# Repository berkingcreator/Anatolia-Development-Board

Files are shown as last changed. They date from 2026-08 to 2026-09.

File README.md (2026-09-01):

# Anatolia Geliştirme Kart Serisi

<p align="center">
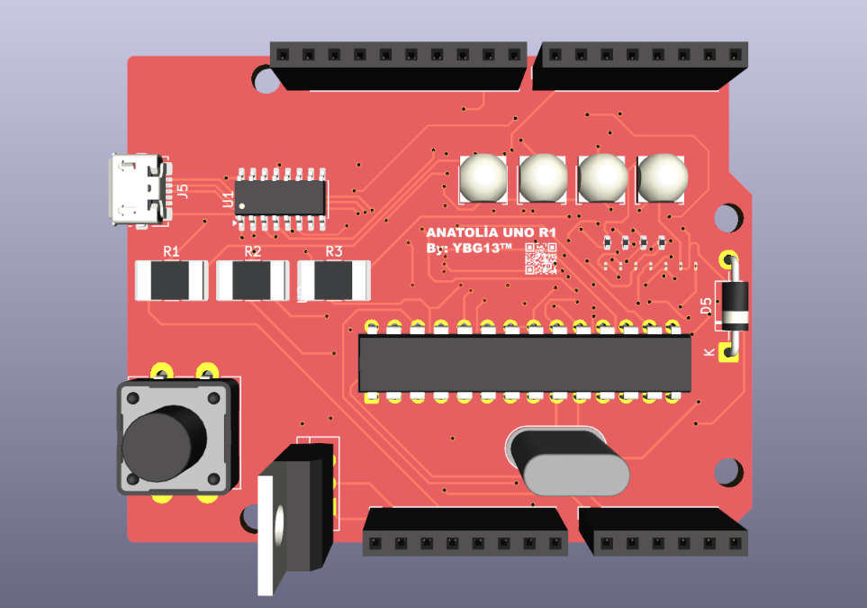
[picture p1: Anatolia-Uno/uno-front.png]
Anatolia Uno Ön Yüz
  
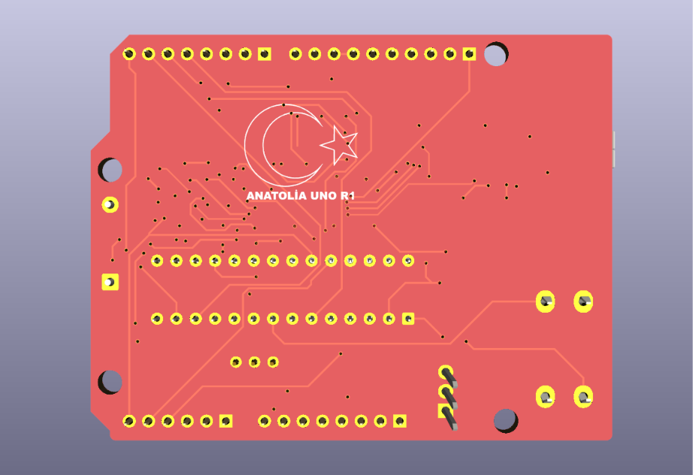
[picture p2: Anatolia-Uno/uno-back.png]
Anatolia Uno Arka Yüz
  
</p>

**Anatolia Geliştirme Kart Serisi**, açık kaynaklı mikrodenetleyici mimarilerini ve AVR (ATmega ve ATtiny) çekirdeklerini temel alan, yerli ve modüler bir geliştirme donanımı ailesidir. Düşük güç tüketimi gerektiren gömülü sistemlerden lojik devre simülasyonlarına, giyilebilir teknolojilerden hafif otonom modüllere kadar geniş bir yelpazede esnek çözümler sunar.

---

## 🚀 Öne Çıkan Özellikler

* **Açık Kaynak Donanım & Mimari:** Tamamen açık kaynaklı şematik ve donanım tasarımı ile özelleştirilebilir yapı.
* **Geniş Çekirdek Desteği:** İhtiyaca göre ölçeklenebilen ATmega328P ve ATtiny85 / ATtiny84 tabanlı yüksek verimli mikrodenetleyici entegrasyonu.
* **Kompakt Form Faktörü:** Minimal alan kaplayan, breadboard ve özel PCB uygulamalarına kolayca entegre edilebilir yapı.
* **Dahili Bootloader Desteği:** Optiboot ve Micronucleus / V-USB bootloader destekleri sayesinde harici programlayıcıya ihtiyaç duymadan USB üzerinden doğrudan kod yükleme.
* **Esnek G/Ç (GPIO) ve PWM:** Kart boyutuna göre optimize edilmiş dahili ADC okuma, SPI/I2C haberleşme ve PWM çıkış yeteneği.

---

## 🛠️ Kart Modelleri

* **Anatolia UNO R1 (ATmega328P):** Serinin temel amiral gemisi. Karmaşık prototipleme süreçleri, sensör ağları ve geniş G/Ç (GPIO) kapasitesi gerektiren standart projeler için geliştirilmiş çok yönlü ana geliştirme kartı.
* **Anatolia Kart G (ATtiny2313A):** Serinin 6 gen şeklindeki kartı. Giyilebilir teknolojiler için ideal.
* **Anatolia Pro Mini (ATtiny85):** Düşük güç tüketimi ve alan kısıtlaması olan gömülü projeler ile özel PCB tasarımlarına doğrudan entegre edilmek için ideal, ultra kompakt geliştirme modülü.
* **Anatolia Micro (ATtiny85):** Giyilebilir teknolojiler, minyatür sistemler ve doğrudan USB programlama gerektiren hızlı pratik çözümler için optimize edilmiş mikro boyutlu kart.
* **Anatolia Lite (ATtiny44A):** Serinin en küçük üyesi. Micro USB. Arduino İDE uyumlu.
* **Anatolia Nano (ATtiny2313A):** Nano boyutlarında tam güç!
*  **Anatolia Micro R2 (ATmega328P):** Anatolia Uno'nun gücü küçük bir kartta! Küçük projeler için ideal.

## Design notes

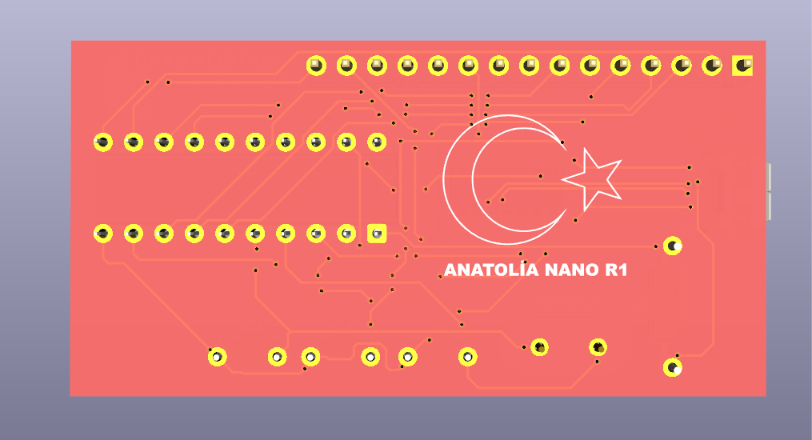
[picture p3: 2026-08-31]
Anatolia-Nano/anatolia-nano-back.png

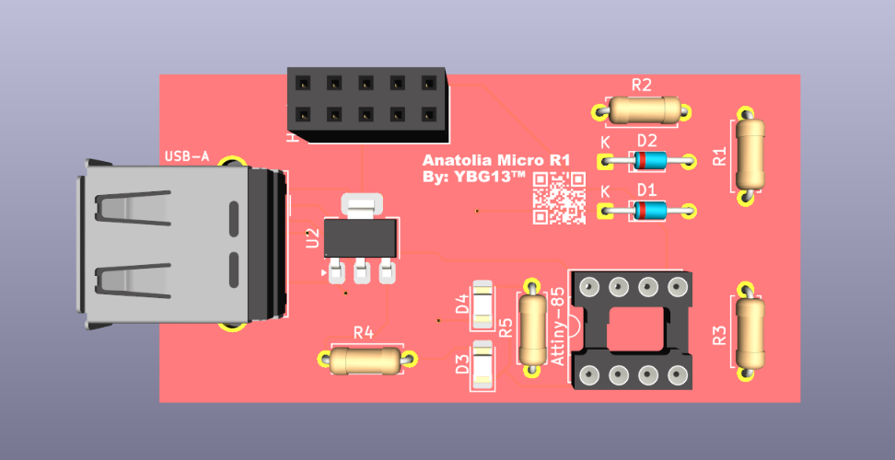
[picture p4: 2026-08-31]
Anatolia-Micro/anatolia-micro.png

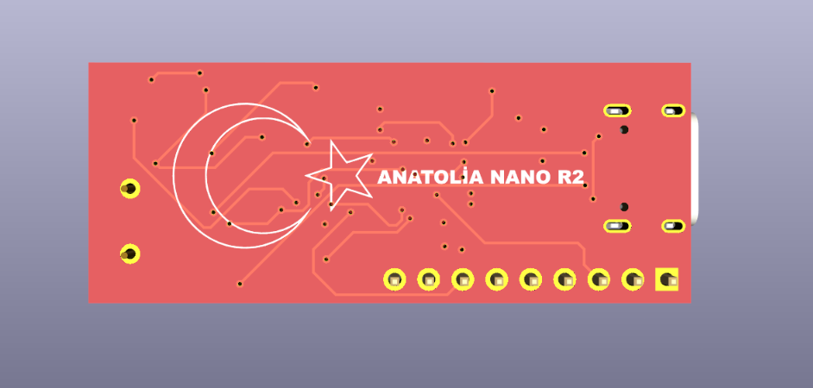
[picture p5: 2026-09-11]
Anatolia-Nano-R2/anatolia-nano-r2-back.png

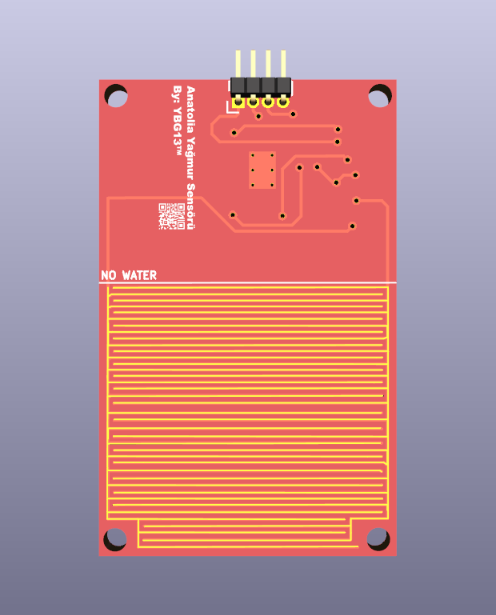
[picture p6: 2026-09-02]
Sensor/Rain-Sensor/rain-sensor.png

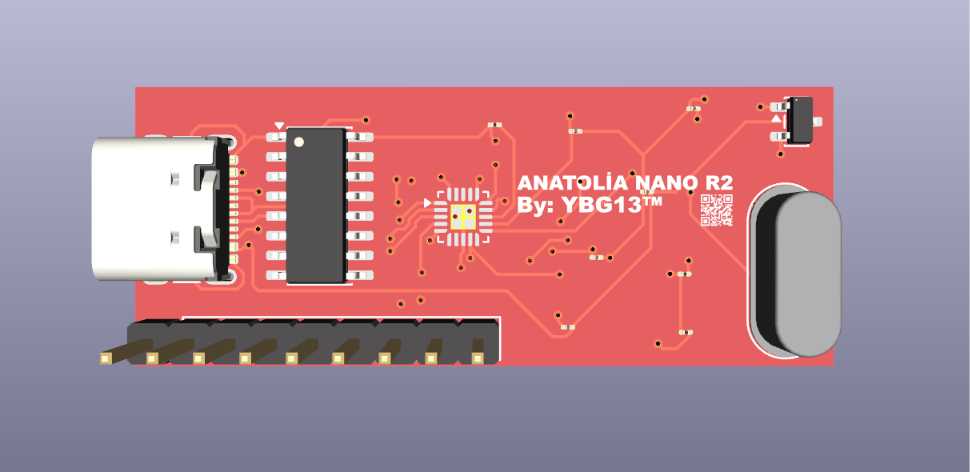
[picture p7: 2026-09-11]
Anatolia-Nano-R2/anatolia-nano-r2.png

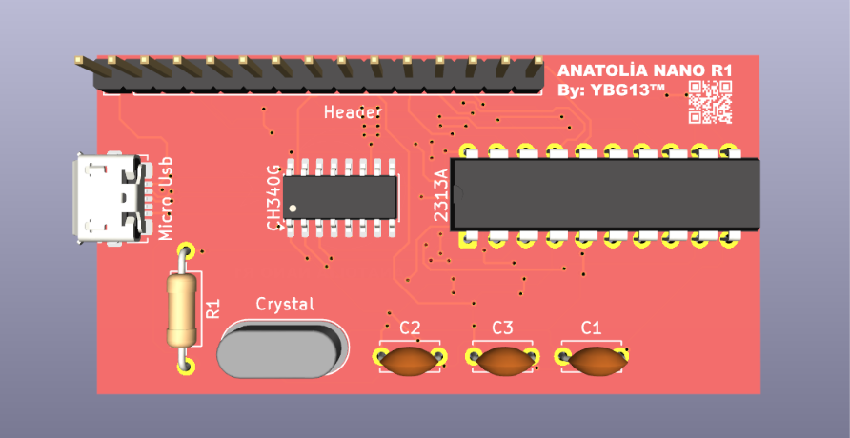
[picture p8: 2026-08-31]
Anatolia-Nano/anatolia-nano-front.png

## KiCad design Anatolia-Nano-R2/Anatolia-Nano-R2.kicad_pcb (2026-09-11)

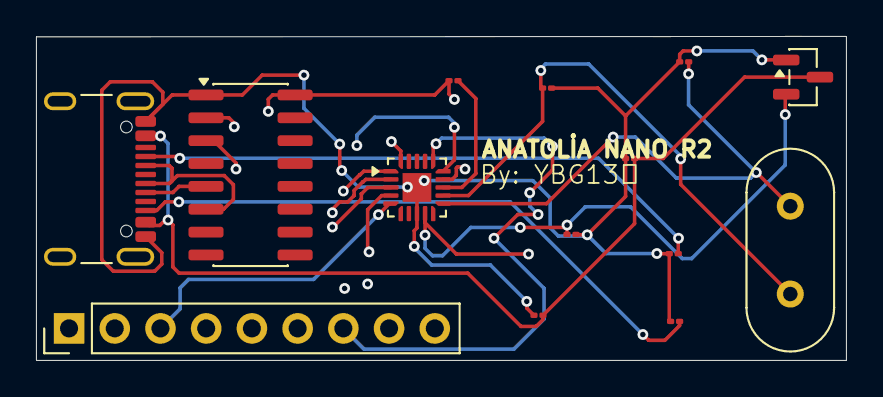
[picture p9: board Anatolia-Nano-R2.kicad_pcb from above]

Board: 4 copper layers, 45.0 x 18.0 mm, 14 parts (0 on the bottom side), 19 nets.

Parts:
C1, C2: 22pF; C_01005_0402Metric
C3: 100nF; C_01005_0402Metric
C4, C5: 1µF; C_01005_0402Metric
J1: USB_C_Receptacle_USB2.0_16P; USB_C_Receptacle_GCT_USB4105-xx-A_16P_TopMnt_Horizontal
J2: Conn_01x09; PinHeader_1x09_P2.54mm_Vertical
R1: 10k; R_01005_0402Metric
R2, R3: 5.1k; R_01005_0402Metric
U1: ATtiny841-MM; QFN-20-1EP_3x3mm_P0.45mm_EP1.6x1.6mm
U2: CH340G; SOIC-16_3.9x9.9mm_P1.27mm
U3: MCP1700x-330xxTT; SOT-23
Y1: 8MHz; Crystal_HC49-4H_Vertical

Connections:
GND: C1.1, C2.2, C3.1, C4.1, C5.2, J1.A1 (GND), J1.A12 (GND), J1.B1 (GND), J1.B12 (GND), J2.2, R2.1, R3.1, U1.8 (GND), U1.21 (GND), U2.1 (GND), U3.1 (GND)
unnamed: J1.A5 (CC1), R2.2
unnamed: J1.B5 (CC2), R3.2
unnamed: C5.1, J2.1, R1.1, U1.9 (VCC), U2.16 (VCC), U3.2 (VO)
unnamed: J2.3, U1.5 (AREF/PA0)
unnamed: J2.4, U1.2 (PA3)
unnamed: J2.5, U1.1 (PA4)
unnamed: J2.6, U1.20 (PA5)
unnamed: J2.7, U1.16 (PA6)
unnamed: J2.8, U1.15 (PA7)
unnamed: J2.9, U1.14 (PB2)
unnamed: U1.4 (PA1), U2.3 (RXD)
unnamed: U1.3 (PA2), U2.2 (TXD)
unnamed: C1.2, U1.11 (XTAL1/PB0), Y1.2
unnamed: C2.1, U1.12 (XTAL2/PB1), Y1.1
unnamed: R1.2, U1.13 (~RESET/PB3)
unnamed: J1.A6 (D+), J1.B6 (D+), U2.5 (UD+)
unnamed: J1.A7 (D-), J1.B7 (D-), U2.6 (UD-)
VCC: C3.2, C4.2, J1.A4 (VBUS), J1.A9 (VBUS), J1.B4 (VBUS), J1.B9 (VBUS), U3.3 (VI)

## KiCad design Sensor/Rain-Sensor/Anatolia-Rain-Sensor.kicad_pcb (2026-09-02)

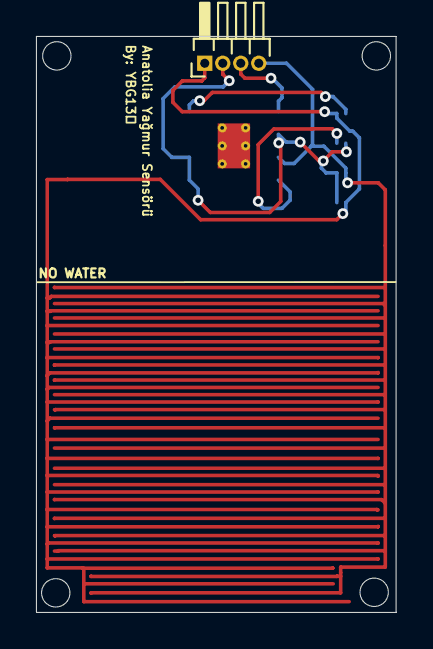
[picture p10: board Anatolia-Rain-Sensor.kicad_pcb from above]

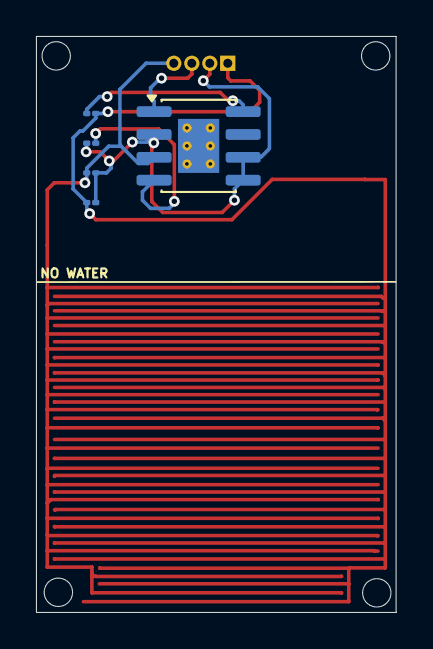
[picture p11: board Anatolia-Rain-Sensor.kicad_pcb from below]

Board: 2 copper layers, 20.0 x 32.0 mm, 6 parts (5 on the bottom side), 6 nets.

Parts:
C1, C2: 100nF; C_01005_0402Metric
J1: Conn_01x04_Pin; PinHeader_1x04_P1.00mm_Horizontal
R1, R2: 10K; R_01005_0402Metric
U1: LM393; SOIC-8-1EP_3.9x4.9mm_P1.27mm_EP2.29x3mm_ThermalVias

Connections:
/3: J1.4, R1.1, U1.3 (+)
/D0: J1.3, U1.1
GND: C2.1, J1.2, R1.2, R2.2, U1.2 (-), U1.5 (+), U1.6 (-)
unnamed: C1.1, U1.8 (V+)
unnamed: C2.2, U1.4 (V-)
VCC: C1.2, J1.1, R2.1

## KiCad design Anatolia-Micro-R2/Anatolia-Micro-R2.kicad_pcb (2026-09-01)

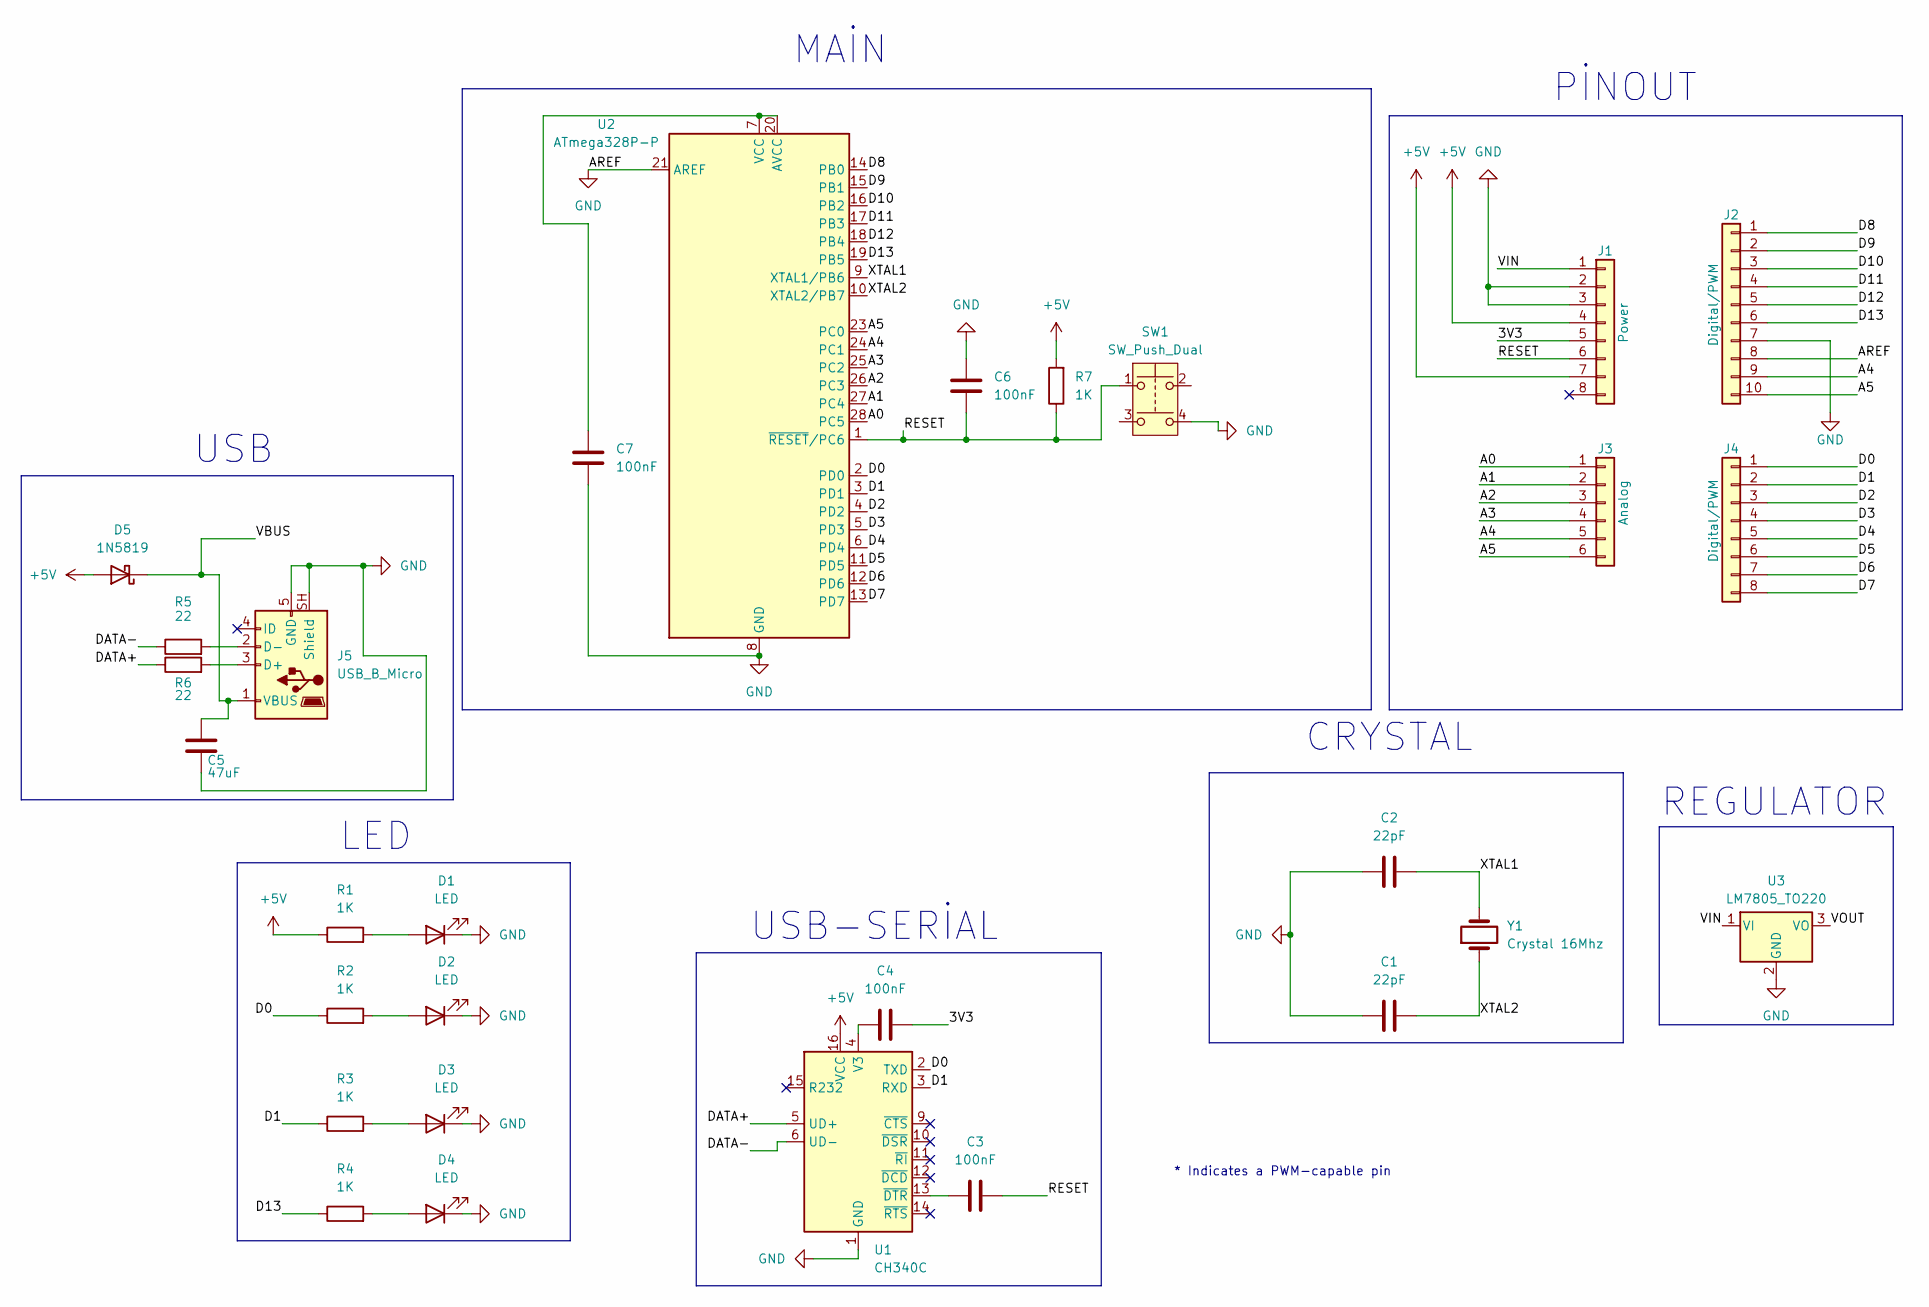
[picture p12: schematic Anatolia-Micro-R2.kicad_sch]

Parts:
C1, C2: 22pF; C_01005_0402Metric
C3, C4, C6, C7: 100nF; C_01005_0402Metric
C5: 47uF; C_01005_0402Metric
D1, D2, D3, D4: LED; LED_0603_1608Metric
D5: 1N5819; D_DO-41_SOD81_P2.54mm_Vertical_CathodeUp
J1: Power; PinSocket_1x08_P2.54mm_Vertical
J2: Digital/PWM; PinSocket_1x10_P2.54mm_Vertical
J3: Analog; PinSocket_1x06_P2.54mm_Vertical
J4: Digital/PWM; PinSocket_1x08_P2.54mm_Vertical
J5: USB_B_Micro; USB_Micro-B_Molex_47346-0001
R1, R2, R3, R4, R7: 1K; R_01005_0402Metric
R5, R6: 22; R_01005_0402Metric
SW1: SW_Push_Dual; SW_Push_SPST_NO_Alps_SKRK
U1: CH340C; SOIC-16_3.9x9.9mm_P1.27mm
U2: ATmega328P-P; TQFP-32_7x7mm_P0.8mm
U3: LM7805_TO220; TO-220-3_Horizontal_TabDown
Y1: Crystal 16Mhz; Crystal_HC49-U-3Pin_Vertical

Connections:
+5V: D5.2 (A), J1.4, J1.7, R1.1, R7.2, U1.16 (VCC)
/3V3: C4.2, J1.5
/A0: J3.1, U2.28 (PC5)
/A1: J3.2, U2.27 (PC4)
/A2: J3.3, U2.26 (PC3)
/A3: J3.4, U2.25 (PC2)
/A4: J2.9, J3.5, U2.24 (PC1)
/A5: J2.10, J3.6, U2.23 (PC0)
/D0: J4.1, R2.1, U1.2 (TXD), U2.2 (PD0)
/D1: J4.2, R3.1, U1.3 (RXD), U2.3 (PD1)
/D2: J4.3, U2.4 (PD2)
/D3: J4.4, U2.5 (PD3)
/D4: J4.5, U2.6 (PD4)
/D5: J4.6, U2.11 (PD5)
/D6: J4.7, U2.12 (PD6)
/D7: J4.8, U2.13 (PD7)
/D8: J2.1, U2.14 (PB0)
/D9: J2.2, U2.15 (PB1)
/D10: J2.3, U2.16 (PB2)
/D11: J2.4, U2.17 (PB3)
/D12: J2.5, U2.18 (PB4)
/D13: J2.6, R4.1, U2.19 (PB5)
/DATA+: R6.1, U1.5 (UD+)
/DATA-: R5.1, U1.6 (UD-)
/RESET: C3.2, C6.1, J1.6, R7.1, SW1.1, U2.1 (~RESET/PC6)
/VBUS: C5.1, D5.1 (K), J5.1 (VBUS)
/VIN: J1.1, U3.1 (VI)
/VOUT: U3.3 (VO)
/XTAL1: C2.2, U2.9 (XTAL1/PB6), Y1.2
/XTAL2: C1.2, U2.10 (XTAL2/PB7), Y1.1
GND: C1.1, C2.1, C5.2, C6.2, C7.2, D1.1 (K), D2.1 (K), D3.1 (K), D4.1 (K), J1.2, J1.3, J2.7, J2.8, J5.5 (GND), J5.SH (Shield), SW1.4, U1.1 (GND), U2.8 (GND), U2.21 (AREF), U2.22 (GND), U3.2 (GND)
unnamed: D1.2 (A), R1.2
unnamed: D2.2 (A), R2.2
unnamed: D3.2 (A), R3.2
unnamed: D4.2 (A), R4.2
unnamed: J5.3 (D+), R6.2
unnamed: J5.2 (D-), R5.2
unnamed: C4.1, U1.4 (V3)
unnamed: C3.1, U1.13 (~DTR)
unnamed: C7.1, U2.7 (VCC), U2.20 (AVCC)

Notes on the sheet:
PİNOUT
REGULATOR
* Indicates a PWM-capable pin
LED
USB-SERİAL
USB
MAİN
CRYSTAL

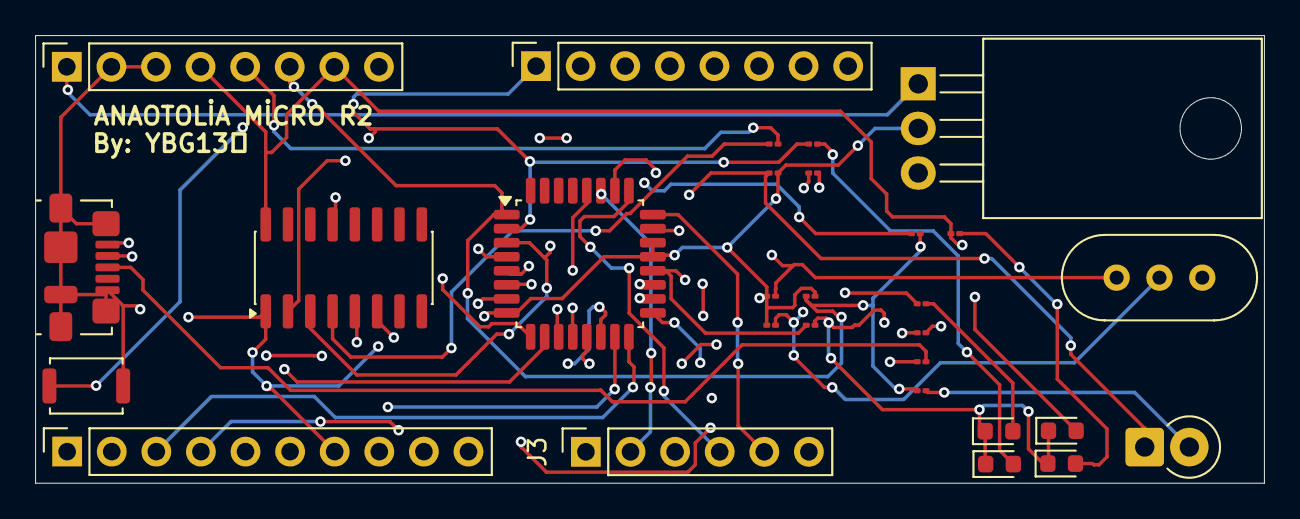
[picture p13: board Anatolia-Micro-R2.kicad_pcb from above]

Board: 6 copper layers, 70.0 x 25.5 mm, 29 parts (0 on the bottom side), 39 nets.

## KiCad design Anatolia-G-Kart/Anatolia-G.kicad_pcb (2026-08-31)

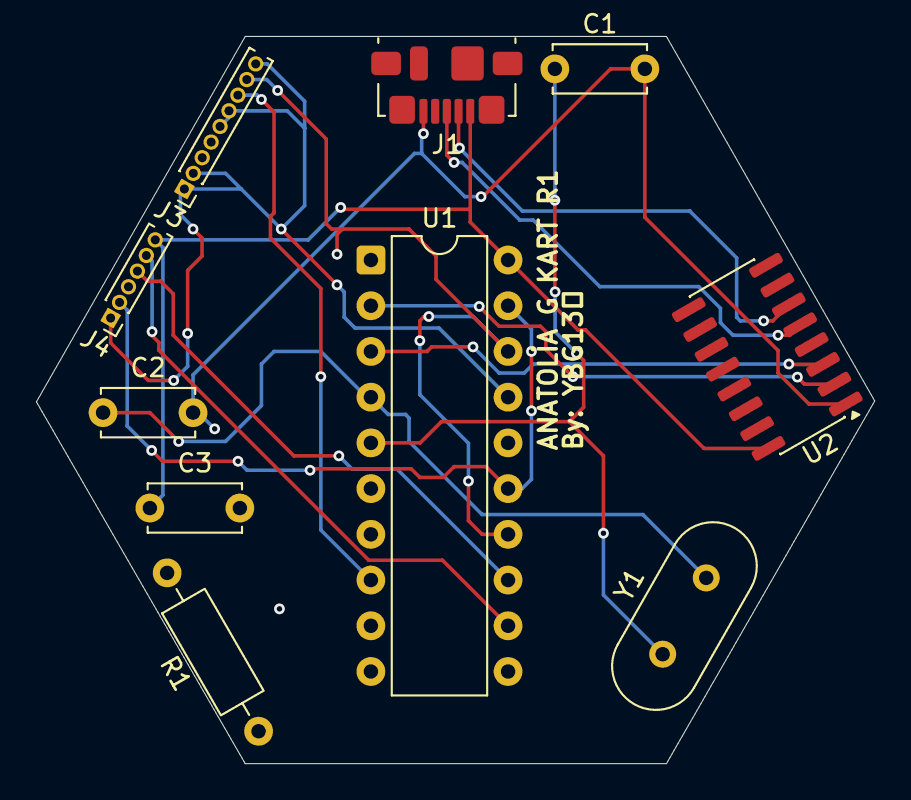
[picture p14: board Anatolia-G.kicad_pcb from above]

Board: 4 copper layers, 46.6 x 40.4 mm, 10 parts (0 on the bottom side), 15 nets.

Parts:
C1, C2: 22pF; C_Disc_D5.0mm_W2.5mm_P5.00mm
C3: 100nF; C_Disc_D5.0mm_W2.5mm_P5.00mm
J1: USB_B_Micro; USB_Micro-B_Molex_47346-0001
J3: Conn_01x09_Pin; PinHeader_1x09_P1.00mm_Vertical
J4: Conn_01x06_Pin; PinHeader_1x06_P1.00mm_Vertical
R1: 10k; R_Axial_DIN0207_L6.3mm_D2.5mm_P10.16mm_Horizontal
U1: ATtiny2313A-P; DIP-20_W7.62mm
U2: CH340G; SOIC-16_3.9x9.9mm_P1.27mm
Y1: Crystal; Crystal_HC49-4H_Vertical

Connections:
unnamed: J1.3 (D+), U2.5 (UD+)
unnamed: J1.2 (D-), U2.6 (UD-)
unnamed: C1.2, C2.2, C3.2, J1.5 (GND), U1.10 (GND), U2.1 (GND)
unnamed: C3.1, J1.1 (VBUS), J4.6, R1.2, U1.20 (VCC), U2.16 (VCC)
unnamed: J3.1, J3.2, J3.5, J3.6, J3.9, J4.1, U1.16 (PB4), U1.17 (PB5)
unnamed: J3.7, U1.8 (PD4)
unnamed: J3.8, J4.3, U1.14 (PB2), U1.18 (PB6)
unnamed: J4.2, U1.15 (PB3), U1.19 (PB7)
unnamed: J4.4, U1.13 (PB1)
unnamed: J4.5, U1.12 (PB0)
unnamed: C1.1, U1.5 (PA0/XTAL1), Y1.1
unnamed: C2.1, U1.4 (PA1/XTAL2), Y1.2
unnamed: R1.1, U1.1 (PA2/~RESET)
unnamed: U1.2 (PD0), U2.2 (TXD)
unnamed: U1.3 (PD1), U2.3 (RXD)

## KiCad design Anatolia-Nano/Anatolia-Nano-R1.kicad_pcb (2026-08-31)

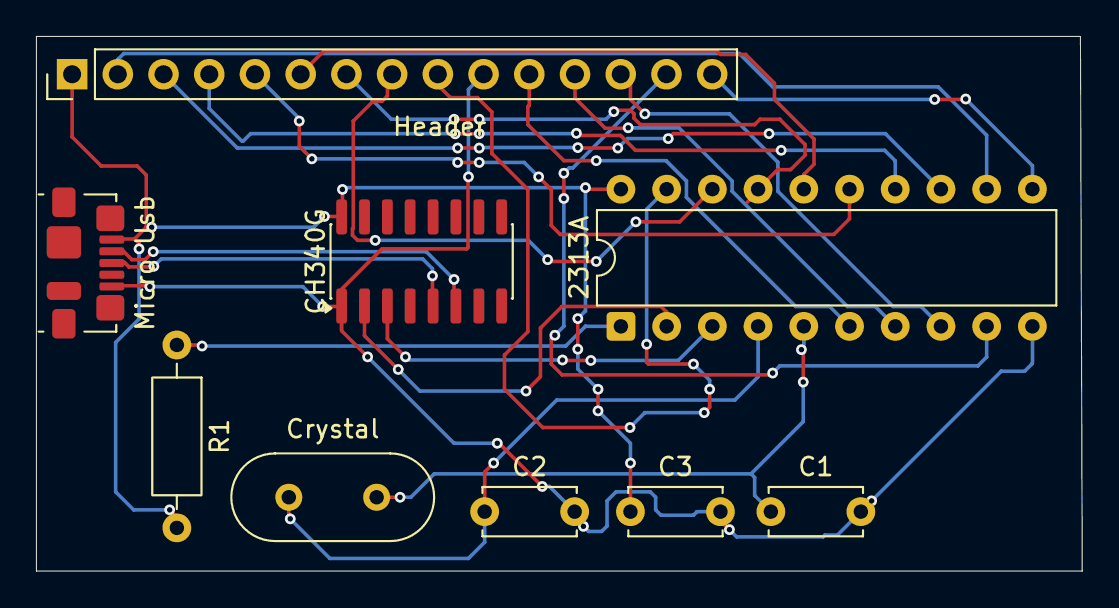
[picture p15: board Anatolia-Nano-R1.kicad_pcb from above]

Board: 2 copper layers, 58.1 x 29.7 mm, 9 parts (0 on the bottom side), 22 nets.

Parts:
2313A: ATtiny2313A-P; DIP-20_W7.62mm
C1, C2: 22pF; C_Disc_D5.0mm_W2.5mm_P5.00mm
C3: 100nF; C_Disc_D5.0mm_W2.5mm_P5.00mm
CH340G: CH340G; SOIC-16_3.9x9.9mm_P1.27mm
Crystal: Crystal; Crystal_HC49-4H_Vertical
Header: Conn_01x15; PinHeader_1x15_P2.54mm_Vertical
Micro Usb: USB_B_Micro; USB_Micro-B_Molex_47346-0001
R1: 10k; R_Axial_DIN0207_L6.3mm_D2.5mm_P10.16mm_Horizontal

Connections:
unnamed: CH340G.5 (UD+), Micro Usb.3 (D+)
unnamed: CH340G.6 (UD-), Micro Usb.2 (D-)
unnamed: 2313A.10 (GND), C1.2, C2.2, C3.2, CH340G.1 (GND), Header.10, Micro Usb.5 (GND)
unnamed: 2313A.20 (VCC), C3.1, CH340G.16 (VCC), Header.1, Micro Usb.1 (VBUS), R1.2
unnamed: 2313A.12 (PB0), Header.2
unnamed: 2313A.13 (PB1), Header.3
unnamed: 2313A.14 (PB2), Header.4
unnamed: 2313A.15 (PB3), Header.5
unnamed: 2313A.16 (PB4), Header.6
unnamed: 2313A.17 (PB5), Header.7
unnamed: 2313A.18 (PB6), Header.8
unnamed: 2313A.19 (PB7), Header.9
unnamed: 2313A.6 (PD2), Header.11
unnamed: 2313A.7 (PD3), Header.12
unnamed: 2313A.8 (PD4), Header.13
unnamed: 2313A.9 (PD5), Header.14
unnamed: 2313A.11 (PD6), Header.15
unnamed: 2313A.5 (PA0/XTAL1), C1.1, Crystal.1
unnamed: 2313A.4 (PA1/XTAL2), C2.1, Crystal.2
unnamed: 2313A.1 (PA2/~RESET), R1.1
unnamed: 2313A.2 (PD0), CH340G.2 (TXD)
unnamed: 2313A.3 (PD1), CH340G.3 (RXD)

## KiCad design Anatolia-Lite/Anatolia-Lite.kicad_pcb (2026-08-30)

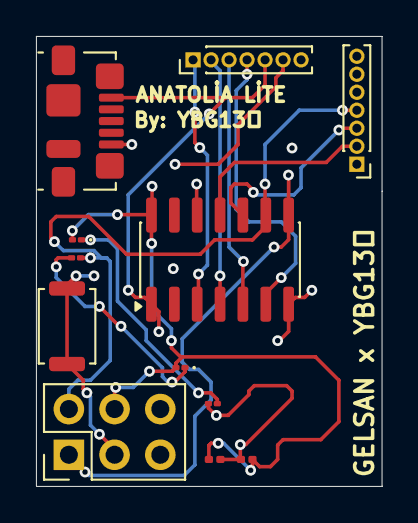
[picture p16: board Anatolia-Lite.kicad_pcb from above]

Board: 4 copper layers, 19.2 x 25.0 mm, 12 parts (0 on the bottom side), 14 nets.

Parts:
C1: 22 µF; C_0201_0603Metric
C2: 0.022 µF; C_0201_0603Metric
D1: CLK; LED_01005_0402Metric
D2: PWR; LED_01005_0402Metric
IC1: ATTINY44A-SSU; SOIC-14_3.9x8.7mm_P1.27mm
ICSP1: M20-9740346; PinHeader_2x03_P2.54mm_Vertical
J1, J2: 7pin-2.54MaleHeader; PinHeader_1x07_P1.00mm_Vertical
R1, R2: 1k; R_01005_0402Metric
RESET1: B3FS-1012P; SW_Push_SPST_NO_Alps_SKRK
USB1: 10118193-0001LF; USB_Micro-B_Molex_47346-0001

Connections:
/PA1: IC1.12 (PA1/ADC1/AIN0/PCINT1), J2.1
/PA2: IC1.11 (PA2/ADC2/AIN1/PCINT2), J2.2
/PA3: IC1.10 (PA3/ADC3/T0/PCINT3), J2.3
/PA4/SCL: IC1.9 (PA4/ADC4/USCK/SCL/T1/PCINT4), ICSP1.2, J2.4, R1.1
/PA5/MISO: IC1.8 (PA5/ADC5/DO/MISO/OC1B/PCINT5), ICSP1.1, J2.5
/PA6/MOSI: IC1.7 (PA6/PCINT6/OC1A/SDA/MOSI/DI/ADC6), ICSP1.5, J2.6
/PA7: IC1.6 (PA7/PCINT7/ICP/OC0B/ADC7), J1.4
/PB1: IC1.3 (PB1/PCINT9/XTAL2), J1.1
/PB2: IC1.5 (PB2/PCINT10/INT0/OC0A/CKOUT), J1.3
/RESET: IC1.4 (PB3/PCINT11/~RESET/dW), ICSP1.3, J1.2, RESET1.1, RESET1.2
/VCC: C1.1, C2.2, IC1.1 (VCC), ICSP1.6, J1.5, R2.2, USB1.1 (VCC)
GND: C1.2, C2.1, D1.2, D2.2, IC1.14 (GND), ICSP1.4, J1.6, USB1.5 (GND)
unnamed: D1.1, R1.2
unnamed: D2.1, R2.1

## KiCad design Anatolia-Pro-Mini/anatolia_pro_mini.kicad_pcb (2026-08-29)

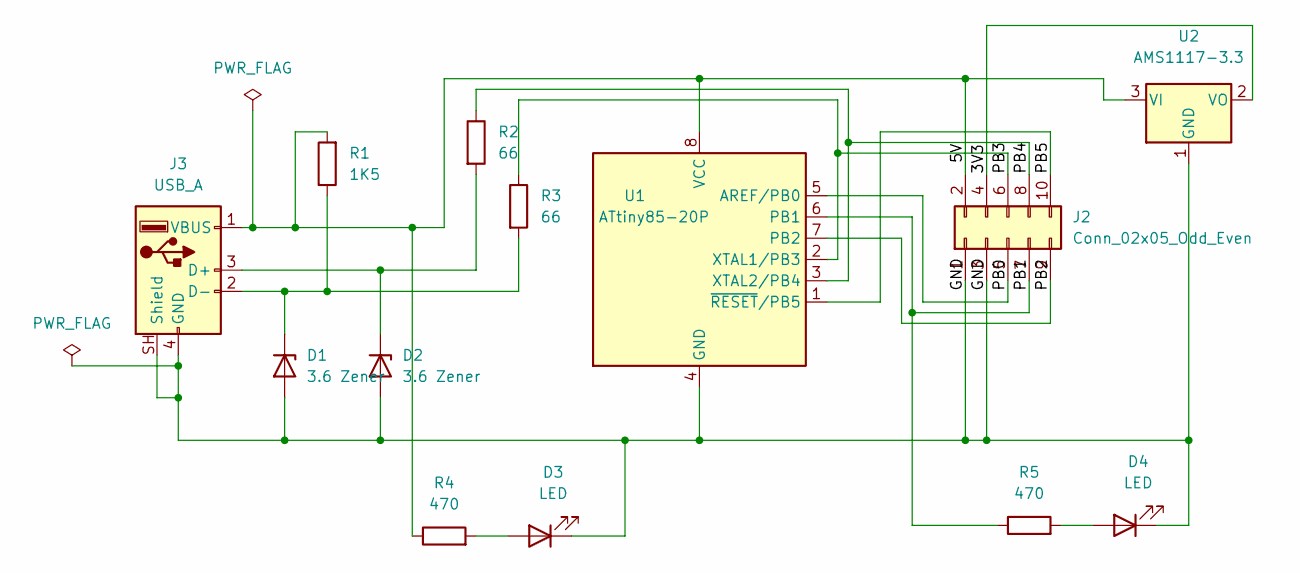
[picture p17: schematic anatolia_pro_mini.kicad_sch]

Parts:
D1, D2: 3.6 Zener; D_0603_1608Metric
D3, D4: LED; LED_1206_3216Metric_Pad1.42x1.75mm_HandSolder
J2: Conn_02x05_Odd_Even; PinSocket_2x05_P2.54mm_Vertical_SMD
J3: USB_A; USB_Micro-B_Molex_47346-0001
R1: 1K5; R_01005_0402Metric
R2, R3: 66; R_01005_0402Metric
R4, R5: 470; R_01005_0402Metric
U1: ATtiny85-20P; DIP-8_W7.62mm_Socket
U2: AMS1117-3.3; SOT-223-3_TabPin2

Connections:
/3V3: J2.4, U2.2 (VO)
/5V: J2.2, J3.1 (VBUS), R1.2, R4.1, U1.8 (VCC), U2.3 (VI)
/GND: D1.2 (A), D2.2 (A), D3.1 (K), D4.1 (K), J2.1, J2.3, J3.4 (GND), J3.SH (Shield), U1.4 (GND), U2.1 (GND)
/PB0: J2.5, U1.5 (AREF/PB0)
/PB1: J2.7, R5.1, U1.6 (PB1)
/PB2: J2.9, U1.7 (PB2)
/PB3: J2.6, R3.1, U1.2 (XTAL1/PB3)
/PB4: J2.8, R2.1, U1.3 (XTAL2/PB4)
/PB5: J2.10, U1.1 (~RESET/PB5)
unnamed: D1.1 (K), J3.2 (D-), R1.1, R3.2
unnamed: D2.1 (K), J3.3 (D+), R2.2
unnamed: D3.2 (A), R4.2
unnamed: D4.2 (A), R5.2

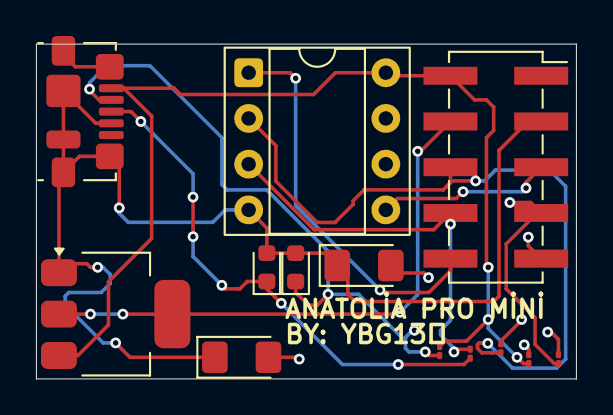
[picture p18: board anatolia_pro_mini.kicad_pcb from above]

Board: 4 copper layers, 30.0 x 18.6 mm, 13 parts (0 on the bottom side), 13 nets.

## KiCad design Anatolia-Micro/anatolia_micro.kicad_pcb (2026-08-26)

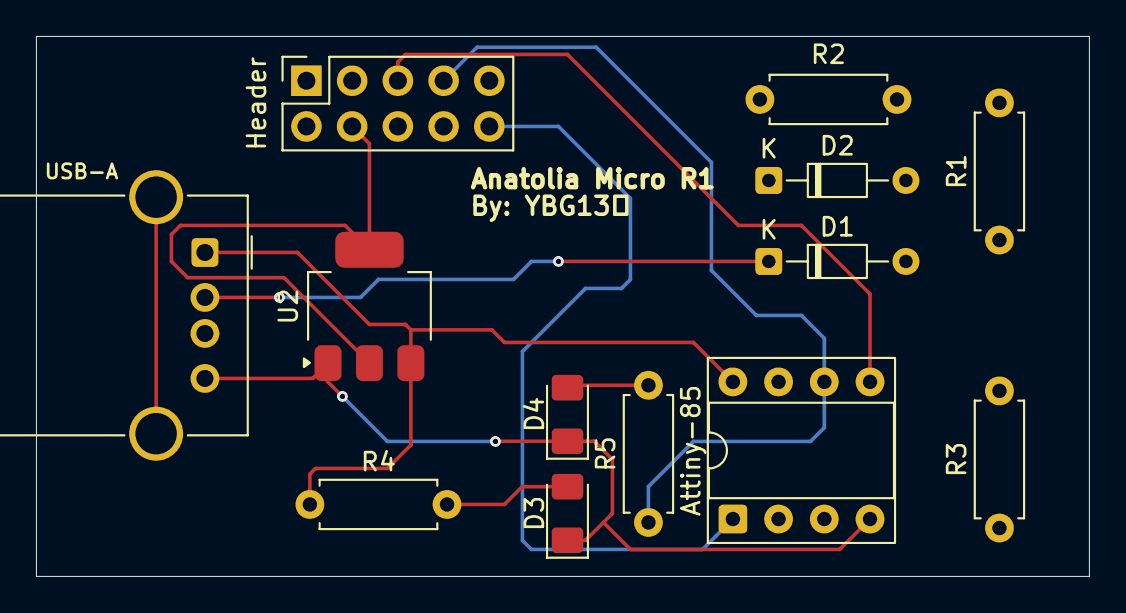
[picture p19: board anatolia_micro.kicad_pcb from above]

Board: 4 copper layers, 58.5 x 30.0 mm, 13 parts (0 on the bottom side), 13 nets.

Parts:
Attiny-85: ATtiny85-20P; DIP-8_W7.62mm_Socket
D1, D2: 3.6 Zener; D_DO-34_SOD68_P7.62mm_Horizontal
D3, D4: LED; LED_1206_3216Metric_Pad1.42x1.75mm_HandSolder
Header: Conn; PinSocket_2x05_P2.54mm_Vertical
R1: 1K5; R_Axial_DIN0207_L6.3mm_D2.5mm_P7.62mm_Horizontal
R2, R3 : 66; R_Axial_DIN0207_L6.3mm_D2.5mm_P7.62mm_Horizontal
R4 , R5: 470; R_Axial_DIN0207_L6.3mm_D2.5mm_P7.62mm_Horizontal
U2: AMS1117-3.3; SOT-223-3_TabPin2
USB-A: USB_A; USB_A_Molex_67643_Horizontal

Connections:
/3V3: Header.4, U2.2 (VO)
/5V: Attiny-85.8 (VCC), Header.2, R1.2, R4.1, U2.3 (VI), USB-A.1 (VBUS)
/GND: Attiny-85.4 (GND), D1.2 (A), D2.2 (A), D3.1 (K), D4.1 (K), Header.1, Header.3, U2.1 (GND), USB-A.4 (GND)
/PB0: Attiny-85.5 (AREF/PB0), Header.5
/PB1: Attiny-85.6 (PB1), Header.7, R5.1
/PB2: Attiny-85.7 (PB2), Header.9
/PB3: Attiny-85.2 (XTAL1/PB3), Header.6, R3.1
/PB4: Attiny-85.3 (XTAL2/PB4), Header.8, R2.1
/PB5: Attiny-85.1 (~RESET/PB5), Header.10
unnamed: D1.1 (K), R1.1, R3.2, USB-A.2 (D-)
unnamed: D2.1 (K), R2.2, USB-A.3 (D+)
unnamed: D3.2 (A), R4.2
unnamed: D4.2 (A), R5.2

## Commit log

2026-08-29 Add anatolia_pro_mini.kicad_prl file
2026-08-30 Anatolia Lite Files
    [Anatolia-Lite.kicad_pcb, Anatolia-Lite.kicad_sch]
2026-09-02 Create Sensor
2026-09-02 Create Rain Sensor
2026-09-02 Rename Ekran görüntüsü 2026-09-02 224905.png to rain-sensor.png
2026-09-02 Rename Ekran görüntüsü 2026-09-02 224917.png to rain-sensor-back.png
